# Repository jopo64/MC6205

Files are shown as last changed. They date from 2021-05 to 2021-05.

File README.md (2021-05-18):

# MC6205
- code for driving a MC6205 with a russian 100x100 pixel plasma tube
- Eagle layout files
- hardware testing code
- weatherstation based on openweathermap.org
- to get full usage of the software, a hardware change must be made before
  - you need a custom eprom for having the ISO-Latin-1 characters

Arduino on ESP32-WROOM

# hackady.io
please see project details at https://hackaday.io/project/178954

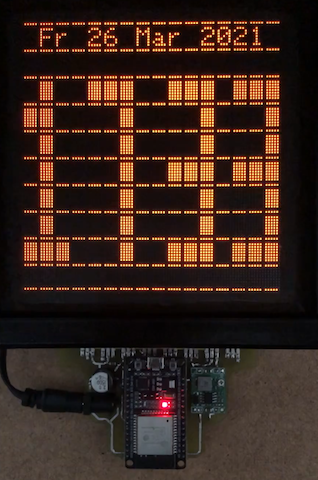
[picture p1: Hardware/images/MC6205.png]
MC6205


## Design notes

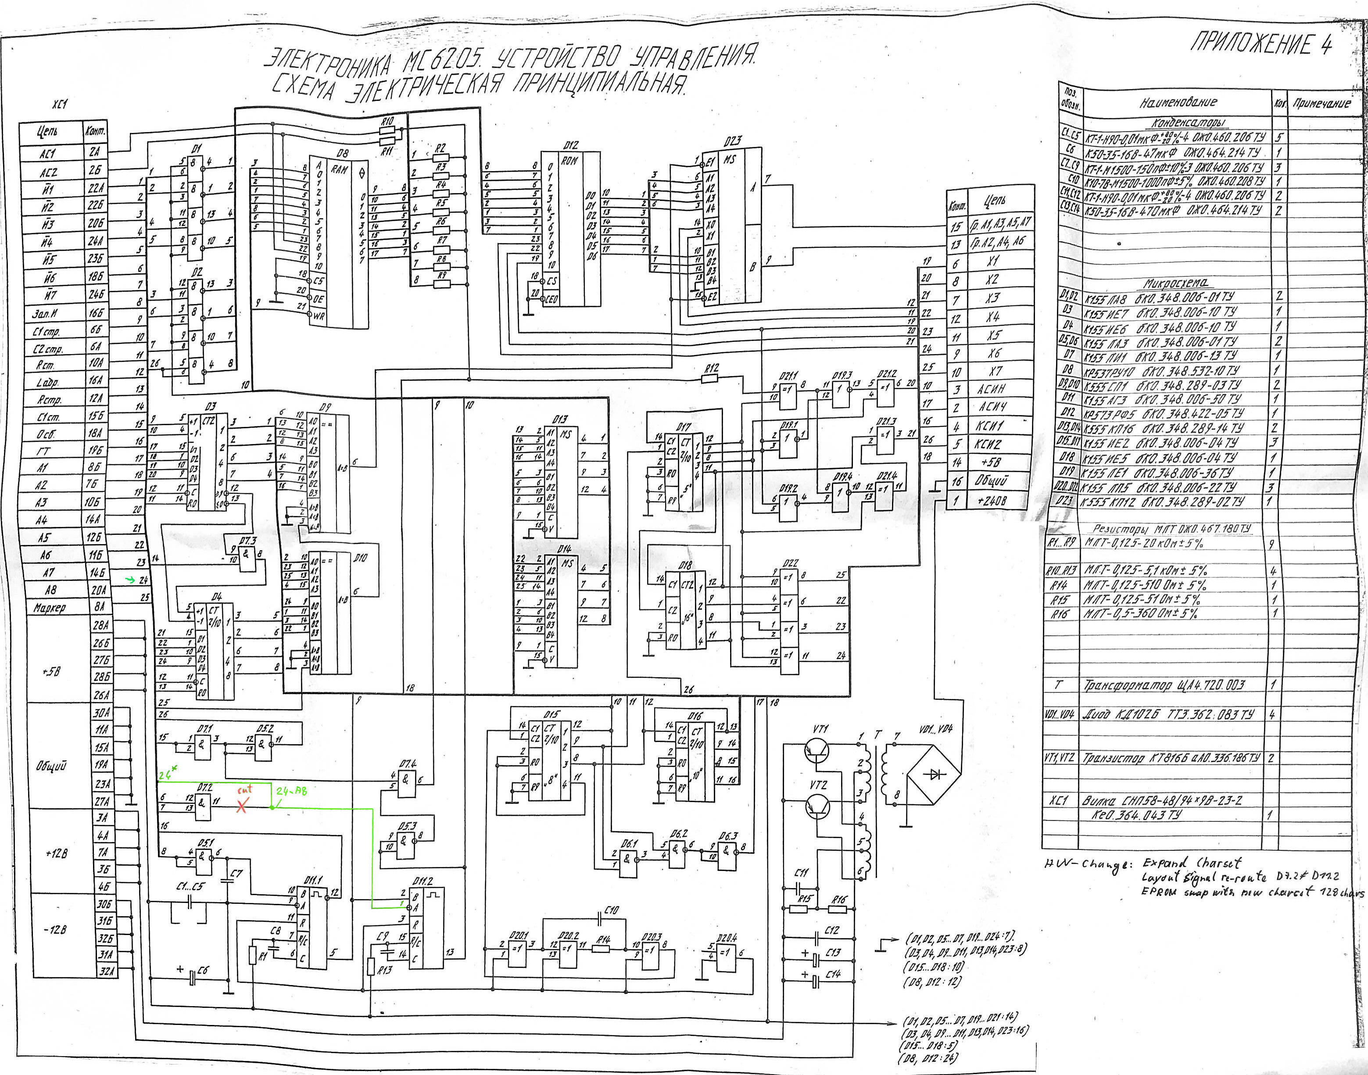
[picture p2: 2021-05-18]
Hardware/schematics/MC6205-Schematics-hack.jpeg

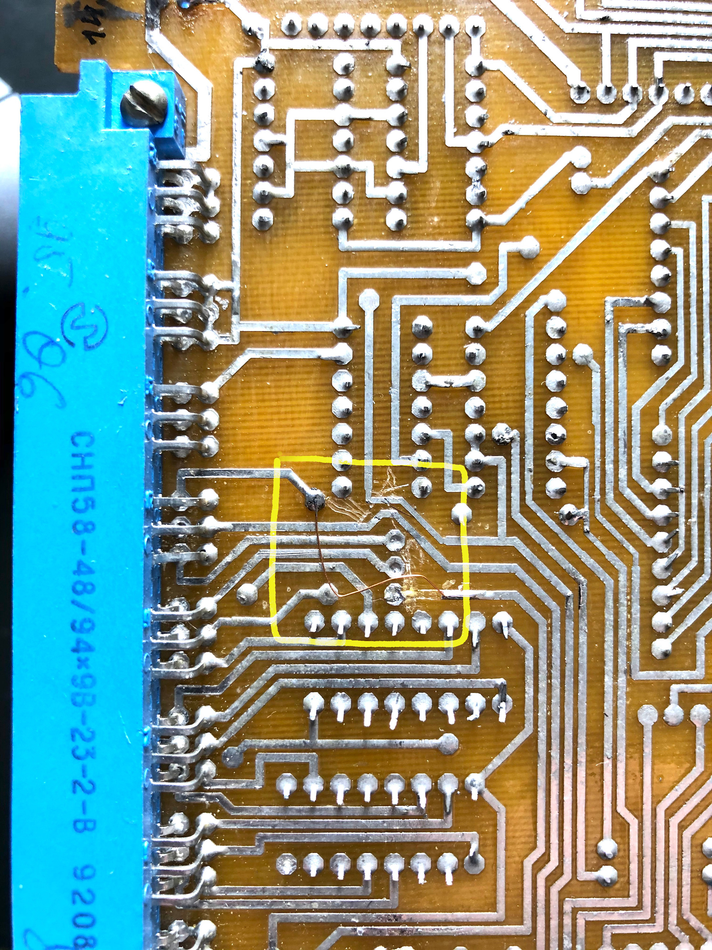
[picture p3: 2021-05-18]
Hardware/schematics/MC6205-hack.jpeg

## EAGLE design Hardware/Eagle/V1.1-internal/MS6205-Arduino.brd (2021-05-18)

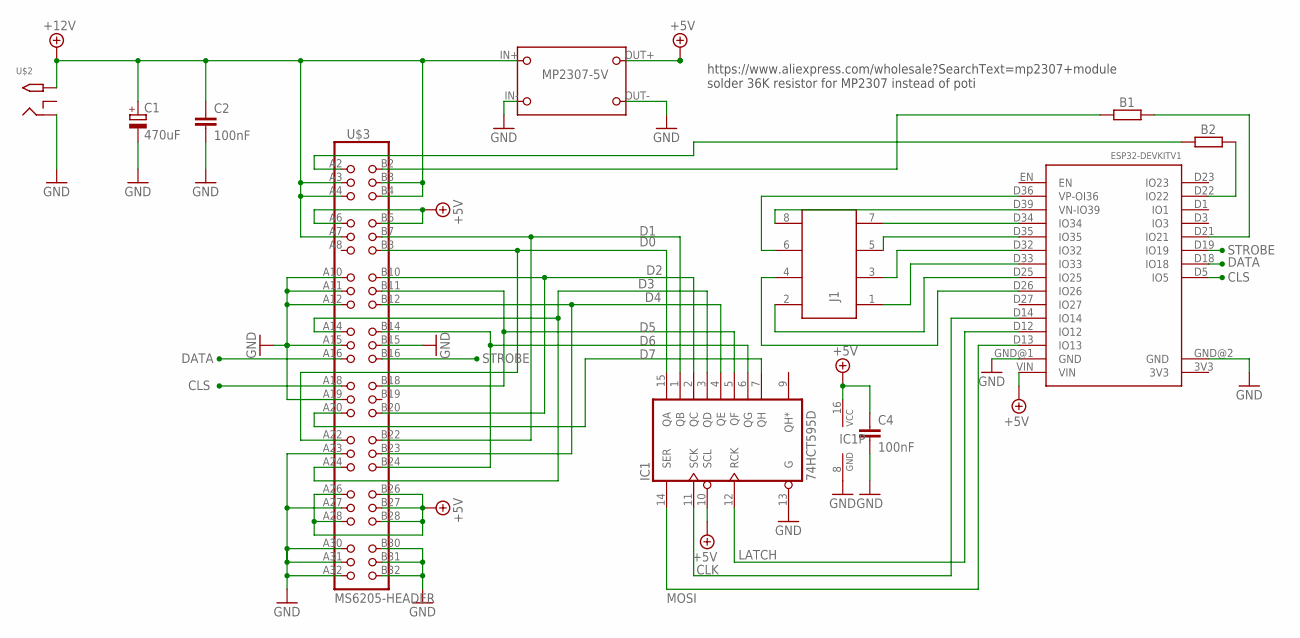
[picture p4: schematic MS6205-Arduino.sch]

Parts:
B1, B2: 0; 0204/5
C1: 470uF; 150CLZ-1010
C2: 100nF; C1206
C4: 100nF; C0805
IC1: 74HCT595D; SO16
J1: 61200822323
MP2307-5V: PWS-MP2307; MP2307-PWS
U$1: ESP32DEVKIT1-REDUCED; ESP32-DEVKIT1-REDUCED
U$2: 2.1MMJACKTHM; PJ-102A
U$3: MS6205-HEADER; MS6205_CONNECTOR_HOLE

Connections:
+12V: C1.+, C2.1, MP2307-5V.IN+, U$2.TIP, U$3.A3, U$3.A4, U$3.A7, U$3.B3, U$3.B4
CLK: IC1.11 (SCK), U$1.D14 (IO14)
CLS: U$1.D5 (IO5), U$3.A18
D0: IC1.15 (QA), U$3.A22, U$3.B8
D1: IC1.1 (QB), U$3.B7, U$3.B22
D2: IC1.2 (QC), U$3.B10, U$3.B20
D3: IC1.3 (QD), U$3.A14, U$3.A24
D4: IC1.4 (QE), U$3.B12, U$3.B23
D5: IC1.5 (QF), U$3.B11, U$3.B18
D6: IC1.6 (QG), U$3.B14, U$3.B24
D7: IC1.7 (QH), U$3.A20
DATA: U$1.D18 (IO18), U$3.A16
GND: C1.-, C2.2, C4.2, IC1.8 (GND), IC1.13 (G), MP2307-5V.IN-, MP2307-5V.OUT-, U$1.GND@1 (GND), U$1.GND@2 (GND), U$2.RING, U$3.A10, U$3.A11, U$3.A12, U$3.A15, U$3.A19, U$3.A23, U$3.A27, U$3.A30, U$3.A31, U$3.A32, U$3.B15, U$3.B30, U$3.B31, U$3.B32
LATCH: IC1.12 (RCK), U$1.D12 (IO12)
MOSI: IC1.14 (SER), U$1.D13 (IO13)
unnamed: B1.1, U$3.B2
unnamed: B2.1, U$3.A2
unnamed: B1.2, U$1.D21 (IO21)
unnamed: B2.2, U$1.D22 (IO22)
unnamed: J1.2, U$1.D25 (IO25)
unnamed: J1.1, U$1.D33 (IO33)
unnamed: J1.4, U$1.D26 (IO26)
unnamed: J1.3, U$1.D32 (IO32)
unnamed: J1.5, U$1.D35 (IO35)
unnamed: J1.7, U$1.D34 (IO34)
unnamed: J1.8, U$1.D39 (VN-IO39)
unnamed: J1.6, U$1.D36 (VP-OI36)
STROBE: U$1.D19 (IO19), U$3.B16
VCC: C4.1, IC1.10 (SCL), IC1.16 (VCC), MP2307-5V.OUT+, U$1.VIN, U$3.A6, U$3.A26, U$3.A28, U$3.B6, U$3.B26, U$3.B27, U$3.B28

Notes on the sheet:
https://www.aliexpress.com/wholesale?SearchText=mp2307+module solder 36K resistor for MP2307 instead of poti

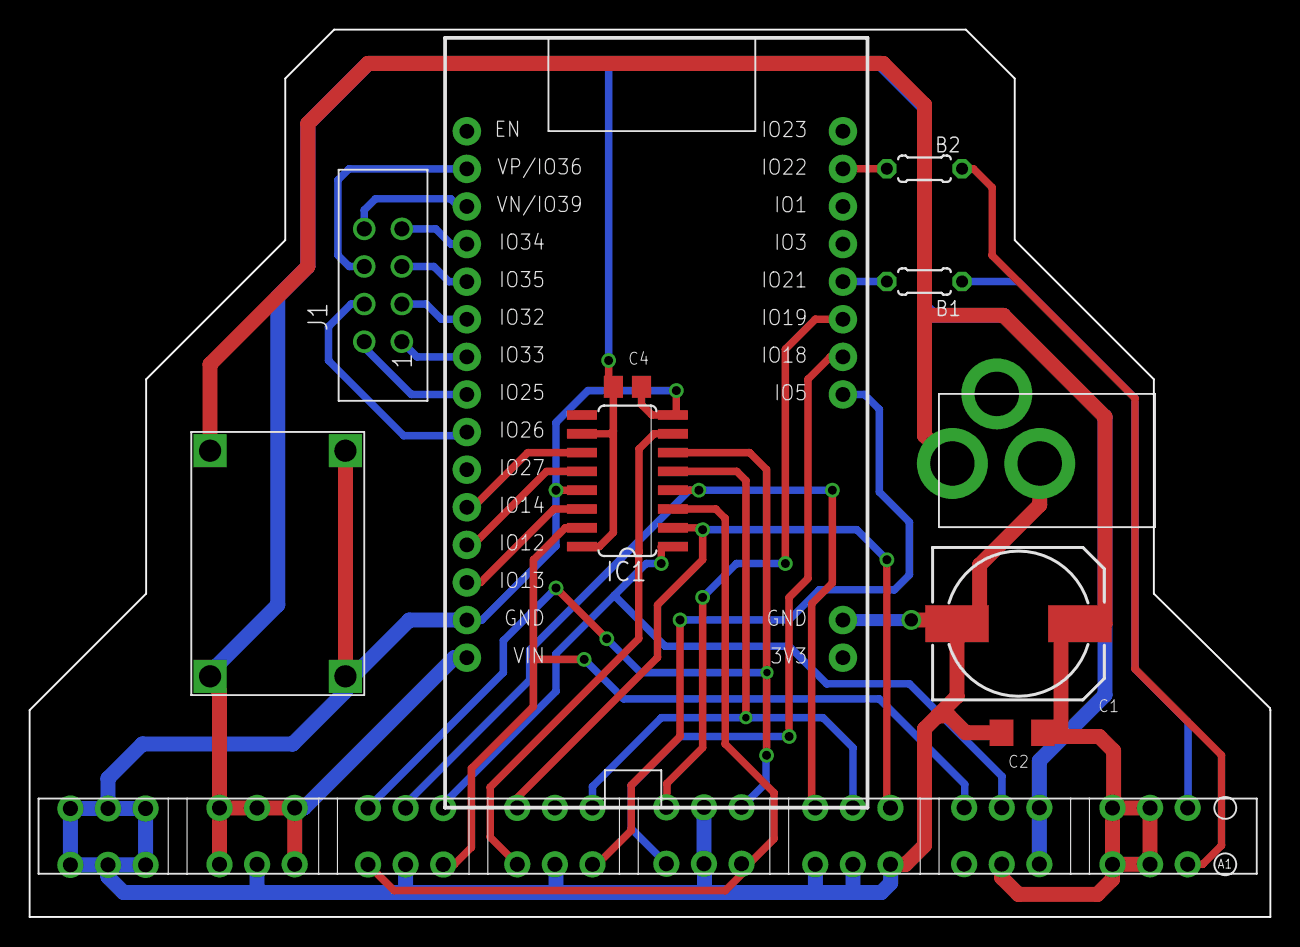
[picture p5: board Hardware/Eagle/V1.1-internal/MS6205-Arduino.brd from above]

Board: 2 copper layers, 83.8 x 59.9 mm, 11 parts (0 on the bottom side), 29 nets.

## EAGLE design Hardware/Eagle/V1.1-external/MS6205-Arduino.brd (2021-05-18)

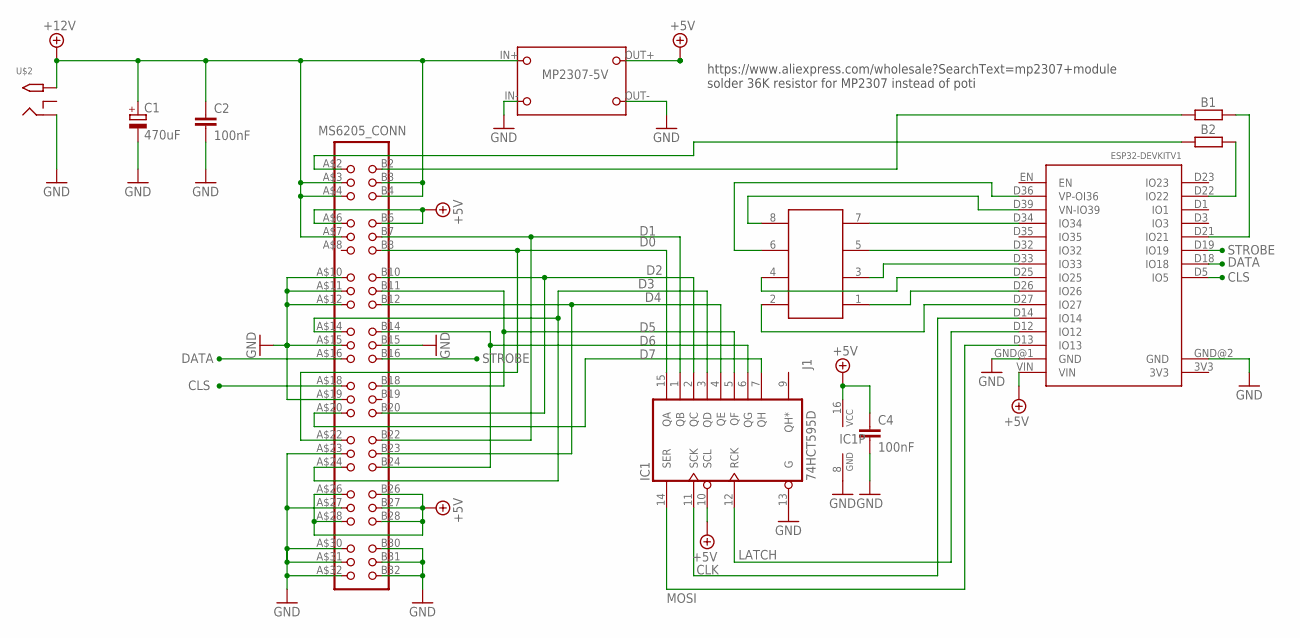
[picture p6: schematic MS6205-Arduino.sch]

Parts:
B1, B2: 0; 0204/5
C1: 470uF; 150CLZ-1010
C2, C4: 100nF; C0805
IC1: 74HCT595D; SO16
J1: 61200822323
MP2307-5V: PWS-MP2307; MP2307-PWS
U$1: ESP32DEVKIT1-REDUCED; ESP32-DEVKIT1-REDUCED
U$2: 2.1MMJACKTHM; PJ-102A
U$4: MS6205_CONN; MS6205_CONNECTOR_SMD

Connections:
+12V: C1.+, C2.1, MP2307-5V.IN+, U$2.TIP, U$4.A$3 (A3), U$4.A$4 (A4), U$4.A$7 (A7), U$4.B3, U$4.B4
CLK: IC1.11 (SCK), U$1.D14 (IO14)
CLS: U$1.D5 (IO5), U$4.A$18 (A18)
D0: IC1.15 (QA), U$4.A$22 (A22), U$4.B8
D1: IC1.1 (QB), U$4.B7, U$4.B22
D2: IC1.2 (QC), U$4.B10, U$4.B20
D3: IC1.3 (QD), U$4.A$14 (A14), U$4.A$24 (A24)
D4: IC1.4 (QE), U$4.B12, U$4.B23
D5: IC1.5 (QF), U$4.B11, U$4.B18
D6: IC1.6 (QG), U$4.B14, U$4.B24
D7: IC1.7 (QH), U$4.A$20 (A20)
DATA: U$1.D18 (IO18), U$4.A$16 (A16)
GND: C1.-, C2.2, C4.2, IC1.8 (GND), IC1.13 (G), MP2307-5V.IN-, MP2307-5V.OUT-, U$1.GND@1 (GND), U$1.GND@2 (GND), U$2.RING, U$4.A$10 (A10), U$4.A$11 (A11), U$4.A$12 (A12), U$4.A$15 (A15), U$4.A$19 (A19), U$4.A$23 (A23), U$4.A$27 (A27), U$4.A$30 (A30), U$4.A$31 (A31), U$4.A$32 (A32), U$4.B15, U$4.B30, U$4.B31, U$4.B32
LATCH: IC1.12 (RCK), U$1.D12 (IO12)
MOSI: IC1.14 (SER), U$1.D13 (IO13)
unnamed: B1.1, U$4.B2
unnamed: B2.1, U$4.A$2 (A2)
unnamed: B1.2, U$1.D21 (IO21)
unnamed: B2.2, U$1.D22 (IO22)
unnamed: J1.2, U$1.D27 (IO27)
unnamed: J1.1, U$1.D26 (IO26)
unnamed: J1.4, U$1.D25 (IO25)
unnamed: J1.3, U$1.D33 (IO33)
unnamed: J1.5, U$1.D32 (IO32)
unnamed: J1.7, U$1.D34 (IO34)
unnamed: J1.8, U$1.D39 (VN-IO39)
unnamed: J1.6, U$1.D36 (VP-OI36)
STROBE: U$1.D19 (IO19), U$4.B16
VCC: C4.1, IC1.10 (SCL), IC1.16 (VCC), MP2307-5V.OUT+, U$1.VIN, U$4.A$6 (A6), U$4.A$26 (A26), U$4.A$28 (A28), U$4.B6, U$4.B26, U$4.B27, U$4.B28

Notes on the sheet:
https://www.aliexpress.com/wholesale?SearchText=mp2307+module solder 36K resistor for MP2307 instead of poti

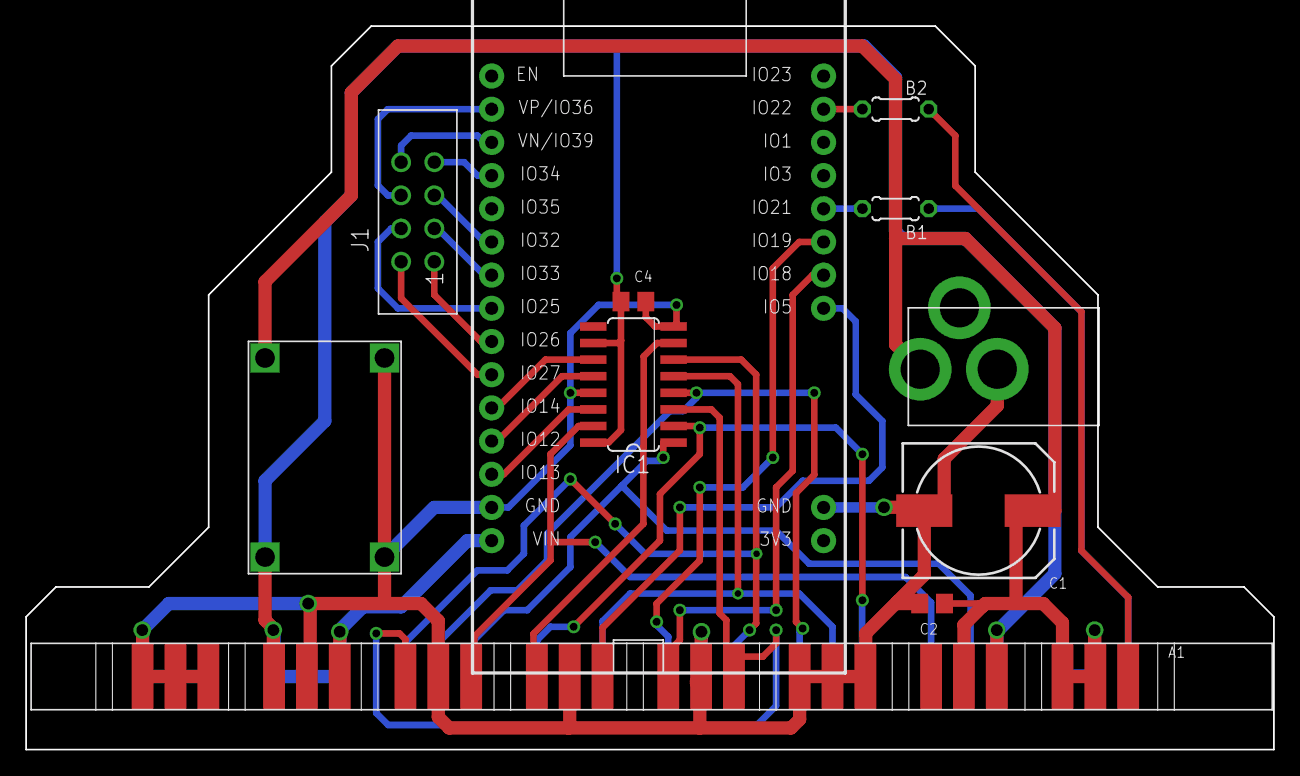
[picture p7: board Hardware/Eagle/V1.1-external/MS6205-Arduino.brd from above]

Board: 2 copper layers, 95.5 x 55.4 mm, 11 parts (0 on the bottom side), 29 nets.

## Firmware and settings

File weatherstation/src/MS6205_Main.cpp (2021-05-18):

//
// MC6205 (MS6205) (c) J.Postert 3/2021 V1.0
//
// Russian gas discharge display with 160 characters 10x16 organized
// the MC6205 has a very limited character-set of only 96 chars, most cyrillic (wasn't usefull for me)
// the code used here, needs a modified characterset-PROM (2716, 2732 or 2816) with US-ASCII + ISO-Latin-1 font enhancements
// MC6205 supports 96 characters, but it has an easter egg... a hidden charset block... 
// for using 128 chars, the hardware has to be changed a bit (one trace to cut and one wire to solder), then! BINgo 8 bit data instead of 7
//
// the charcter set is organized in 3 x 32 chars == 96, plus the hidden one in the EPROM which is in total 4 x 32 chars == 128
//
// some similar projects:
// https://dekatronpc.com/index.php/%D0%9C%D0%A16205
// https://hackaday.io/project/172342-mc6205-ms6205-display
// https://github.com/holzachr/MS6205-arduino-library
// https://radiokot.ru/forum/viewtopic.php?p=402815#p402815
// https://www.youtube.com/watch?v=_xHFLyv6XAk
// https://www.youtube.com/watch?v=5NktqEwgCs4
//
// ESP32: WLAN 2,4GHz only
//

#include <WiFi.h>



// MC6205 hardware pins to Arduino (internal PCB)
const char cursorPin      = 18;   // 16A
const char updatePin      = 19;   // 16B
const char clearScreenPin = 5;    // 18A

// shift register pins
const char latchPin       = 12;   // Latch  | Pin 12 of 74LS595 (ST_CP)
const char clockPin       = 14;   // CLK    | Pin 11 of 74LS595 (SH_CP)
const char dataPin        = 13;   // MOSI   | Pin 14 of 74LS595 (DS)



const char MAXCHAR  = 160;
const char ROWSIZE  = 16;

String MessageBuffer;

bool SwitchClockFlg = 0;
char BigClockCntr = 0;

unsigned long tMillis;
unsigned long tMillis_saved[10];  // array for saved milliseconds

char SERDEBUG = 0;                // debug infos to serial

// XXX   X   XXX  XXX
//   X  XX   X X  X X
//   X   X   X X  X X
// XXX   X   X X  XXX
// X     X   X X  X X
// X     X   X X  X X
// XXX  XXX  XXX  XXX

const char zero[]   = {95,95,95,95,0,95,95,0,95,95,0,95,95,0,95,95,0,95,95,95,95};
const char one[]    = {0,95,0,95,95,0,0,95,0,0,95,0,0,95,0,0,95,0,95,95,95};
const char two[]    = {95,95,95,0,0,95,0,0,95,95,95,95,95,0,0,95,0,0,95,95,95};
const char three[]  = {95,95,95,0,0,95,0,0,95,95,95,95,0,0,95,0,0,95,95,95,95};
const char four[]   = {95,0,95,95,0,95,95,0,95,95,95,95,0,0,95,0,0,95,0,0,95};
const char five[]   = {95,95,95,95,0,0,95,0,0,95,95,95,0,0,95,0,0,95,95,95,95};
const char six[]    = {95,95,95,95,0,0,95,0,0,95,95,95,95,0,95,95,0,95,95,95,95};
const char seven[]  = {95,95,95,0,0,95,0,0,95,0,0,95,0,0,95,0,0,95,0,0,95};
const char eight[]  = {95,95,95,95,0,95,95,0,95,95,95,95,95,0,95,95,0,95,95,95,95};
const char nine[]   = {95,95,95,95,0,95,95,0,95,95,95,95,0,0,95,0,0,95,95,95,95};

const char posNum[] = {32,33,34,48,49,50,64,65,66,80,81,82,96,97,98,112,113,114,128,129,130,144,145,146};

const char frame[]  = {0,1,2,3,4,5,6,7,8,9,10,11,12,13,14,15,31,47,63,79,95,111,127,143,159,158,157,
                       156,155,154,153,152,151,150,149,148,147,146,145,144,128,112,96,80,64,48,32,16
                      };



// Prototypes
void displayNumber(char number, char shift);
void updateShiftRegister(uint8_t c);
void DisplayHelloWorld(void);
void TestDisplayNumbers(void);
void DisplayOneChar(void);
void DisplayMessage(String Message, int startPos);
void ScreenTest(void);
void DisplayCharacterSet(void);
void hideCursor(void);
void sendData();
void setPosition();
void setColon(void);
void DisplayClear();
void DisplayDateTime(void);
void DisplayDate(void);
void DisplayBigClock(void);
String utf8toIso1(String utf8string);

// WiFi stuff
extern void WiFi_init();
extern void NTP_printLocalTime(int offset, int mode);
extern void WeatherReport(void);


void setup() {
  if(SERDEBUG==1)
    Serial.begin(115200);

  pinMode(clearScreenPin, OUTPUT);
  pinMode(cursorPin, OUTPUT);
  pinMode(updatePin, OUTPUT);
  pinMode(latchPin, OUTPUT);
  pinMode(dataPin, OUTPUT);
  pinMode(clockPin, OUTPUT);

  digitalWrite(cursorPin,HIGH);
  digitalWrite(updatePin,HIGH);
  digitalWrite(clearScreenPin,LOW);
  delay(30);
  digitalWrite(clearScreenPin,HIGH);

  // initialize WiFi stack
  WiFi_init();

  // weather info from openweathermap
  WeatherReport();
  delay(4000);
  DisplayClear();
  tMillis_saved[2] = millis()+15000;
}

void lloop() {
  DisplayClear();
  DisplayCharacterSet();
  delay(2000);
  DisplayClear();
  DisplayHelloWorld();
  delay(2000);
  DisplayClear();
  ScreenTest();
  delay(2000);
  DisplayClear();
  WeatherReport();
  delay(2000);
}

void loop() {

  tMillis = millis();
  char tmpbuff[160];

  if(tMillis >= tMillis_saved[4]+88000) {
    DisplayClear();
    DisplayHelloWorld();
    delay(2000);
    DisplayClear();
    tMillis_saved[4] = millis();
  }

  // some text
  if(tMillis >= tMillis_saved[3]+120000) {
    //sprintf(tmpbuff, "The lipogrammatic novel Ella Minnow Pea by Mark Dunn is built entirely around the \"quick brown fox\" pangram and its inventor. It depicts a fictional country");
    sprintf(tmpbuff, "Die Umlaute \'ä\',\'ö\',\'ü\' und \'ß\' gehören zu einer Besonderheit der deutschen Sprache. Sie erweitern das Alphabet um vier weitere Buchstaben. Wie schön.");
    DisplayMessage(utf8toIso1(tmpbuff), 0);
    delay(8000);
    DisplayClear();
    tMillis_saved[3] = millis();
  }
  
  // display charcter-set
  if(tMillis >= tMillis_saved[1]+96000) 
  {
    tMillis_saved[1] = millis();
    DisplayClear();
    DisplayCharacterSet();
    delay(4000);
    DisplayClear();
  }

  // switch clocks
  if(tMillis >= tMillis_saved[2]+10000) {
    SwitchClockFlg = !SwitchClockFlg;
    DisplayClear();
    BigClockCntr = 0;
    tMillis_saved[2] = millis();
  }

  // seconds update of clock
  if(tMillis >= tMillis_saved[0]+999)
  {
    tMillis_saved[0] = millis();
    if(SwitchClockFlg == 1)
      DisplayDateTime();
    else {
      DisplayBigClock();
    }
  }

  // Weather report
  if(tMillis >= tMillis_saved[5]+20000)
  {
    DisplayClear();
    WeatherReport();
    tMillis_saved[5] = millis();
    delay(6000);
    DisplayClear();
  }
}


// showtime
void DisplayDateTime(void) {
  NTP_printLocalTime(49,0);
}

void DisplayDate(void) {
  NTP_printLocalTime(1,1);
}

// show our character set 
void DisplayCharacterSet(void)
{
  for (int i=0; i < MAXCHAR; i++) {
    updateShiftRegister(i);
    setPosition();
    updateShiftRegister(i);
    sendData();
    delay(5);
  }
 hideCursor();
}


// show our character set 
void ScreenTest(void)
{
  for (int i=0; i < MAXCHAR; i++) {
    updateShiftRegister(i);
    setPosition();
    updateShiftRegister(95);
    sendData();
    delay(1);
  }
 hideCursor();
}


void DisplayOneChar(void)
{
  updateShiftRegister(1);
  setPosition();
  updateShiftRegister(25);
  sendData();
  updateShiftRegister(2);
  setPosition();
  updateShiftRegister(4);
  setPosition();
  updateShiftRegister(24);
  sendData();
  updateShiftRegister(6);
  setPosition();
}

// test numbers
// "0" = Pos1, "4" = Pos2, "9" = Pos3, "13" = Pos4  Use this for Clocks
// displayNumber(Number to be displayed at Position 0 - 159)
void TestDisplayNumbers(void)
{
  int dly = 200;
  displayNumber(0,0);
  delay(dly);
  displayNumber(1,4);
  delay(dly);
  displayNumber(2,9);
  delay(dly);
  displayNumber(3,13);
  
  delay(dly*5);
  displayNumber(4,0);
  delay(dly);
  displayNumber(5,4);
  delay(dly);
  displayNumber(6,9);
  delay(dly);
  displayNumber(7,13);
  
  delay(dly*5);
  displayNumber(8,0);
  delay(dly);
  displayNumber(9,4);
  delay(dly);
  displayNumber(0,9);
  delay(dly);
  displayNumber(0,13);
}


void DisplayBigClock(void)
{
  struct tm timeinfo;
 
  getLocalTime(&timeinfo);
  
  if(BigClockCntr++ <= 4) {
    if(BigClockCntr == 1) { // date needs no update every second, so one shot
      DisplayDate();        // show date in first row
      displayNumber(timeinfo.tm_hour/10%10,0);
      delay(50);
      displayNumber(timeinfo.tm_hour%10,4);
      delay(50);
      displayNumber(timeinfo.tm_min/10%10,9);
      delay(50);
      displayNumber(timeinfo.tm_min%10,13);
    }
  } 
  else
  {
    NTP_printLocalTime(1,0);          // show date and time in first row
    displayNumber(timeinfo.tm_min/10%10,0);
    delay(5);
    displayNumber(timeinfo.tm_min%10,4);
    delay(5);
    displayNumber(timeinfo.tm_sec/10%10,9);
    delay(5);
    displayNumber(timeinfo.tm_sec%10,13);
  }
  if(BigClockCntr > 12)
    BigClockCntr = 0;
}


//
// display free Text (utf8 possible)
//
void DisplayMessage(String Message, int startPos)
{
  for (int i=0; i<Message.length(); ++i) {
    updateShiftRegister(startPos+i);
    setPosition();
    updateShiftRegister(Message[i]-32);
    sendData();
  }
  hideCursor();
}

//
// display greetings
//
void DisplayHelloWorld(void)
{   
  DisplayMessage("Hello", 18);
  delay(300);
  DisplayMessage("World", 38);
  delay(500);
  DisplayMessage("-- this is --", 66);
  delay(400);
  DisplayMessage("MC6205", 85);
  delay(500);
  DisplayMessage("Greets from", 114);
  delay(250);
  DisplayMessage("Germany", 132);
  delay(500);
  for (int i=0; i<48; i++) {
    updateShiftRegister(frame[i]);
    setPosition();
    updateShiftRegister(127); // heart symbol
    sendData();
    delay(20);
  }
  hideCursor();
  delay(1000);
}



// generate big number to be displayed 
void displayNumber(char number, char shift)
{
  for (int i=0; i< 21; i++) 
  {
    updateShiftRegister((posNum[i]+shift));
    setPosition();
    if(number==0) updateShiftRegister(zero[i]);
    else if(number==1) updateShiftRegister(one[i]);
    else if(number==2) updateShiftRegister(two[i]);
    else if(number==3) updateShiftRegister(three[i]);
    else if(number==4) updateShiftRegister(four[i]);
    else if(number==5) updateShiftRegister(five[i]);
    else if(number==6) updateShiftRegister(six[i]);
    else if(number==7) updateShiftRegister(seven[i]);
    else if(number==8) updateShiftRegister(eight[i]);
    else if(number==9) updateShiftRegister(nine[i]);
    sendData();
  }
}

//  Update shift register
void updateShiftRegister(unsigned char c)
{
  digitalWrite(latchPin, LOW);
  shiftOut(dataPin, clockPin, MSBFIRST, c);
  digitalWrite(latchPin, HIGH);
}

// update/strobe char
void sendData()
{ 
  digitalWrite(updatePin,LOW);
  digitalWrite(updatePin,HIGH);
}

// strobe cursor position
void setPosition()
{
  digitalWrite(cursorPin,LOW);
  digitalWrite(cursorPin,HIGH);
}

// clear screen 
void DisplayClear()
{
  digitalWrite(clearScreenPin,LOW);
  delay(30);
  digitalWrite(clearScreenPin,HIGH);
  hideCursor();
}

// kick cursor to outer space
void hideCursor(void)
{
  updateShiftRegister(160);
  setPosition();
}


//
// simple utf8 to iso latin-1 mapping and cleanup
//
String utf8toIso1(String utf8string) 
{
  for (int i=0; i < utf8string.length()-1; ++i) {
    char c   = utf8string[i];
    char cnv = utf8string[i+1];
    
    if (c == 0xC2) {
      utf8string.remove(i,1);
      if(cnv==0xa7) utf8string[i+1] = 148;         // utf8 §
      else if(cnv==0xb0) utf8string[i+1] = 149;    // utf8 °
      else if(cnv==0xb5) utf8string[i+1] = 150;    // utf8 µ
    }
    if (c == 0xC3) {
      if(SERDEBUG==1) {
        Serial.print("Content+1:");
        Serial.println(cnv,HEX);
      }

      if(cnv==0x80) utf8string[i+1] = 'A';       // utf8 À
      else if(cnv==0x81) utf8string[i+1] = 'A';  // utf8 À
      else if(cnv==0x82) utf8string[i+1] = 'A';  // utf8 À
      else if(cnv==0x83) utf8string[i+1] = 'A';  // utf8 Ã
      else if(cnv==0x84) utf8string[i+1] = 132;  // utf8 Ä
      else if(cnv==0x85) utf8string[i+1] = 'A';  // utf8 Å
      else if(cnv==0x86) utf8string[i+1] = 'A';  // utf8 Æ
      else if(cnv==0x87) utf8string[i+1] = 'C';  // utf8 Ç
      else if(cnv==0x88) utf8string[i+1] = 'E';  // utf8 È
      else if(cnv==0x89) utf8string[i+1] = 'E';  // utf8 É
      else if(cnv==0x8a) utf8string[i+1] = 'E';  // utf8 Ê
      else if(cnv==0x8b) utf8string[i+1] = 'E';  // utf8 Ë
      else if(cnv==0x8c) utf8string[i+1] = 'I';  // utf8 Ì
      else if(cnv==0x8d) utf8string[i+1] = 'I';  // utf8 Í
      else if(cnv==0x8e) utf8string[i+1] = 'I';  // utf8 Î
      else if(cnv==0x8f) utf8string[i+1] = 'I';  // utf8 Ï
      else if(cnv==0x92) utf8string[i+1] = 'O';  // utf8 Ò
      else if(cnv==0x93) utf8string[i+1] = 'O';  // utf8 Ó
      else if(cnv==0x94) utf8string[i+1] = 'O';  // utf8 Ô
      else if(cnv==0x95) utf8string[i+1] = 'O';  // utf8 Õ
      else if(cnv==0x96) utf8string[i+1] = 133;  // utf8 Ö
      else if(cnv==0x9c) utf8string[i+1] = 134;  // utf8 Ü
      else if(cnv==0x9f) utf8string[i+1] = 131;  // utf8 ß
      else if(cnv==0xa0) utf8string[i+1] = 135;  // utf8 à
      else if(cnv==0xa1) utf8string[i+1] = 136;  // utf8 á
      else if(cnv==0xa2) utf8string[i+1] = 137;  // utf8 â
      else if(cnv==0xa3) utf8string[i+1] = 'a';  // utf8 ã
      else if(cnv==0xa4) utf8string[i+1] = 128;  // utf8 ä
      else if(cnv==0xa5) utf8string[i+1] = 'a';  // utf8 å
      else if(cnv==0xa6) utf8string[i+1] = 'a';  // utf8 æ
      else if(cnv==0xa7) utf8string[i+1] = 144;  // utf8 ç
      else if(cnv==0xa8) utf8string[i+1] = 138;  // utf8 è
      else if(cnv==0xa9) utf8string[i+1] = 139;  // utf8 é
      else if(cnv==0xaa) utf8string[i+1] = 140;  // utf8 ê
      else if(cnv==0xab) utf8string[i+1] = 'e';  // utf8 ë
      else if(cnv==0xb9) utf8string[i+1] = 141;  // utf8 ù
      else if(cnv==0xba) utf8string[i+1] = 142;  // utf8 ú
      else if(cnv==0xbb) utf8string[i+1] = 143;  // utf8 û
      else if(cnv==0xbc) utf8string[i+1] = 130;  // utf8 ü
      else if(cnv==0xbd) utf8string[i+1] = 'y';  // utf8 ý
      else if(cnv==0xbf) utf8string[i+1] = 'y';  // utf8 ÿ
      else if(cnv==0xb2) utf8string[i+1] = 142;  // utf8 ò
      else if(cnv==0xb3) utf8string[i+1] = 143;  // utf8 ó
      else if(cnv==0xb4) utf8string[i+1] = 144;  // utf8 ô
      else if(cnv==0xb5) utf8string[i+1] = 'o';  // utf8 õ
      else if(cnv==0xb6) utf8string[i+1] = 129;  // utf8 ö

      if(SERDEBUG==1) {
        Serial.print("utf8: ");
        Serial.print(c,HEX);
        Serial.print(" : ");
        Serial.println(utf8string.charAt(i+1),HEX);
      }

      utf8string.remove(i,1);    // remove C3

    } // remove all other utf >= C4
    if (c==0xC4 || c==0xC5 || c==0xC6 || c==0xC7 || c==0xC8 || c==0xC9) {
      utf8string.remove(i,2);
    }
  }
  
  return utf8string;
}

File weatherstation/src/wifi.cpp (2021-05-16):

//
// using ideas from:
// https://github.com/sstaub/NTP
// https://randomnerdtutorials.com/esp32-http-get-open-weather-map-thingspeak-arduino
//
// When calling configtime with NTP server name (like "pool.ntp.org"), make sure you have a valid DNS settings
// A valid DNS will be available if you started the network connection with default parameters (like Wifi.begin(ssid,sspass)), 
// but will not be available in case you started your network connection with WiFi.config(IP,gateway,subnet) (used to get fix IP)
// without giving it valid DNS -> WiFi.config(IP,GW,SUB,DNS1,DNS2)!!!
//
// MUST use version 1.0: arduino-libraries/Arduino_JSON @ ^0.1.0
//

#include <WiFi.h>
#include <HTTPClient.h>
#include <Arduino_Json.h>
#include <TinyXML.h>

const char ssid[]      = "<your ssid>";
const char password[]  = "<pwd>";
const char ntpServer[] = "pool.ntp.org";
const char hostname[]  = "ESP32-Nimo";
const char tzinfo[]    = "WEST-1DWEST-2,M3.5.0/02:00:00,M10.5.0/03:00:00";   // Western European Time

String openWeatherMapApiKey = "<api key";            // your own id, has to be requested from openweathermap
String openWeatherMapcityid = "";
//String openWeatherMapcityids[] = {"2911288", "524894", "8224785"};    //  "Hamburg: 2911288";  // Moscow: 524894 Mumbai: 1275339, Waterloo: 8224785
// some city id's from openWeatherMap website

//String openWeatherMapcityids[] = {"258543","258569","258575","282342","288131","283180","2911288","1275339","281997"};
String openWeatherMapcityids[] = {"2911288","3169272","2967096","2909313","2909325","2909335","2909344","2909347","2909350","2909356","2909364","2909386","2909402","2909418","2909430","2909433","2909437","2909444","2909445","2909460","2909461","2909489","2909491","2909497","2909544","2909587","2909601","2909615","2909618","2909623","2909636","2909695","2909696","2909755","2909756","2909761","2909762","2909764","2909781","2909821","2909865","2909873","2909877","2909880","2909884","2909886","2909892","2909908","2909912","2909915","2909916","2909926","2909941","2909944","2909968","2909969","2909973","2910037","2910046","2910047","2910048","2910049","2910051","2910055","2910068","2910099","2910108","2910121","2910135","2910140","2910141","2910146","2910167","2910168","2910171","2910172","2910178","2910181","2910231","2910269","2910271","2910273","2910275","2910278","2910280","2910282","2910283","2910289","2910292","2910302","2910310","2910324","2910342","2910344","2910363","2910381","2910384","2910385","2910390","2910391","2910403","2910407","2910410","2910419","2910451","2910456","2910463","2910469","2910474","2910483","2910484","2910488","2910493","2910514","2910552","2910560","2910575","2910624","2910633","2910638","2910639","2910648","2910649","2910652","2910663","2910667","2910675","2910684","2910685","2910686","2910694","2910706","2910709","2910711","2910720","2910724","2910748","2910760","2910761","2910762","2910776","2910777","2910791","2910814","2910831","2910863","2910875","2910881","2910898","2910900","2910902","2910921","2910935","2910949","2910966","2910971","2910973","2910985","2910986","2910992","2911007","2911010","2911013","2911044","2911051","2911072","2911073","2911074","2911077","2911082","2911087","2911099","2911144","2911145","2911167","2911173","2911189","2911214","2911218","2911230","2911233","2911240","2911242","2911243","2911246","2911250","2911251","2911257","2911259","2911260","2911266","2911271","2911275","2911276","2911282","2911283","2911285","2911287","2911288","2911293","2911296","2911297","2911298","2911300","2911301","2911306","2911308","2911314","2911318","2911322","2911325","2911360","2911362","2911364","2911369","2911379","2911384","2911389","2911395","2911404","2911408","2911419","2911423","2911426","2911443","2911461","2911463","2911464","2911483","2911491","2911514","2911520","2911521","2911522","2911530","2911533","2911544","2911556","2911561","2911566","2911575","2911579","2911580","2911584","2911631","2911634","2911640","2911641","2911648","2911664","2911665","2911667","2911682","2911683","2911691","2911695","2911700","2911725","2911729","2911739","2911760","2911765","2911767","2911769","2911771","2911775","2911794","2911795","2911813","2911825","2911831","2911833","2911834","2911855","2911909","2911910","2911911","2911916","2911917","2911935","2911938","2911940","2911953","2911955","2911960","2911964","2911965","2911983","2911987","2912018","2912053","2912106","2912120","2912122","2912158","2912159","2912160","2912167","2912168","2912177","2912184","2912195","2912236","2912266","2912272","2912309","2912312","2912319","2912320","2912347","2912351","2912357","2912367","2912368","2912386","2912392","2912400","2912405","2912417","2912448","2912457","2912481","2912495","2912496","2912509","2912533","2912534","2912539","2912541","2912547","2912573","2912577","2912594","2912604","2912605","2912618","2912621","2912646","2912649","2912681","2912711","2912744","2912745","2912753","2912758","2912782","2912790","2912801","2912807","2912810","2912811","2912820","2912826","2912829","2912834","2912850","2912858","2912863","2912921","2912932","2912938","2912943","2912948","2912961","2912966","2912983","2913000","2913025","2913046","2913050","2913064","2913069","2913153","2913177","2913192","2913195","2913200","2913210","2913221","2913224","2913225","2913229","2913233","2913244","2913274","2913275","2913279","2913280","2913286","2913290","2913292","2913296","2913297","2913303","2913328","2913335","2913357","2913366","2913375","2913376","2913381","2913384","2913385","2913387","2913394","2913395","2913405","2913406","2913408","2913414","2913417","2913421","2913425","2913428","2913431","2913433","2913437","2913445","2913446","2913449","2913452","2913453","2913461","2913466","2913472","2913478","2913480","2913492","2913525","2913532","2913535","2913537","2913543","2913555","2913558","2913565","2913571","2913587","2913592","2913598","2913600","2913609","2913625","2913626","2913627","2913631","2913657","2913660","2913661","2913673","2913675","2913676","2913677","2913679","2913681","2913687","2913689","2913692","2913693","2913694","2913701","2913708","2913711","2913713","2913719","2913721","2913731","2913737","2913738","2913743","2913745","2913752","2913761","2913773","2913782","2913783","2913788","2913797","2913803","2913814","2913818","2913825","2913838","2913841","2913847","2913848","2913855","2913880","2913884","2913888","2913890","2913891","2913892","2913905","2913906","2913913","2913915","2913918","2913922","2913942","2913972","2914035","2914057","2914064","2914101","2914105","2914121","2914122","2914125","2914137","2914144","2914146","2914159","2914169","2914177","2914186","2914188","2914191","2914208","2914215","2914252","2914263","2914275","2914279","2914292","2914304","2914309","2914316","2914347","2914426","2914428","2914432","2914457","2914465","2914522","2914543","2914548","2914560","2914562","2914642","2914655","2914657","2914660","2914661","2914689","2914741","2914746","2914756","2914769","2914789
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

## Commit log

2021-05-18 add hardware PCB schematics and Eagle files
    [MS6205-Arduino.brd, MS6205-Arduino.sch]
2021-05-18 small fix of port definitions
    [MS6205_Main.cpp, MS6205_Test.cpp]
2021-05-18 small fix of port definition
    [MS6205_Test.cpp]

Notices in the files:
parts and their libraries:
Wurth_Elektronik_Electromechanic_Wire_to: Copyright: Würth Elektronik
